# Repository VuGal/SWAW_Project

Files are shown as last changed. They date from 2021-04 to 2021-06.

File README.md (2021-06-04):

# SWAW_Project
Weather station project for SWAW course.

Android directory - contains the source code of the Android app which fetches the weather info from the server (along with prediction data)

Azure directory - contains the scripts related to weather prediction and database operations

Nucleo directory - contains the STM32 Nucleo source code (based on STM32CubeIDE) which is responsible for the communication with sensors and CAN communication with Raspberry Pi

PCB - contains the files related to the PCBs created for the project

Raspberry Pi - contains the Python scripts which are responsible for fetching the weather info via CAN bus and sending it to the server

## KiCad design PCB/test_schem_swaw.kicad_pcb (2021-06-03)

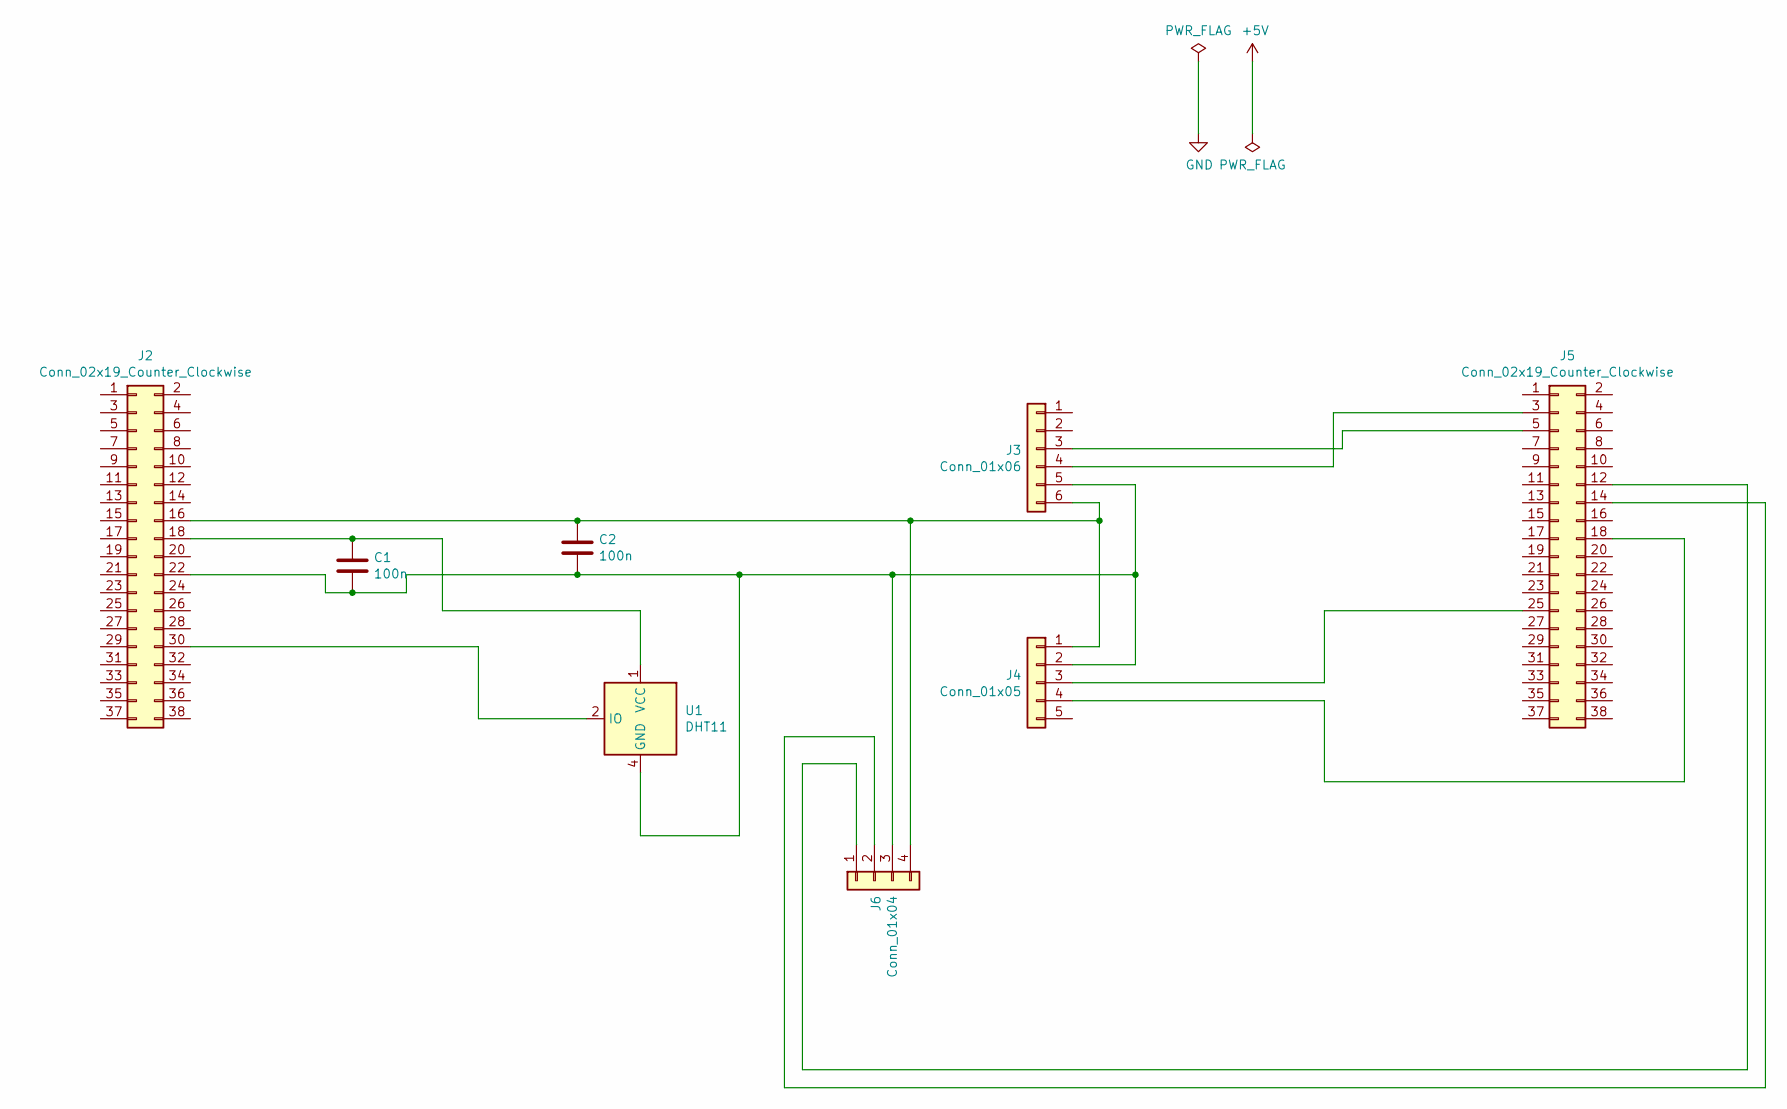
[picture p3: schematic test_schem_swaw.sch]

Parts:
C1, C2: 100n; C_Disc_D7.5mm_W4.4mm_P5.00mm
J2, J5: Conn_02x19_Counter_Clockwise; PinSocket_2x19_P2.54mm_Vertical
J3: Conn_01x06; PinSocket_1x06_P2.54mm_Vertical
J4: Conn_01x05; PinSocket_1x05_P2.54mm_Vertical
J6: Conn_01x04; PinSocket_1x04_P2.54mm_Vertical
U1: DHT11; Aosong_DHT11_5.5x12.0_P2.54mm

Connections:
unnamed: C1.1, J2.18, U1.1 (VCC)
unnamed: C1.2, C2.2, J2.22, J3.5, J4.2, J6.3, U1.4 (GND)
unnamed: C2.1, J2.16, J3.6, J4.1, J6.4
unnamed: J2.30, U1.2 (IO)
unnamed: J3.3, J5.5
unnamed: J3.4, J5.3
unnamed: J4.3, J5.25
unnamed: J4.4, J5.18
unnamed: J5.12, J6.1
unnamed: J5.14, J6.2

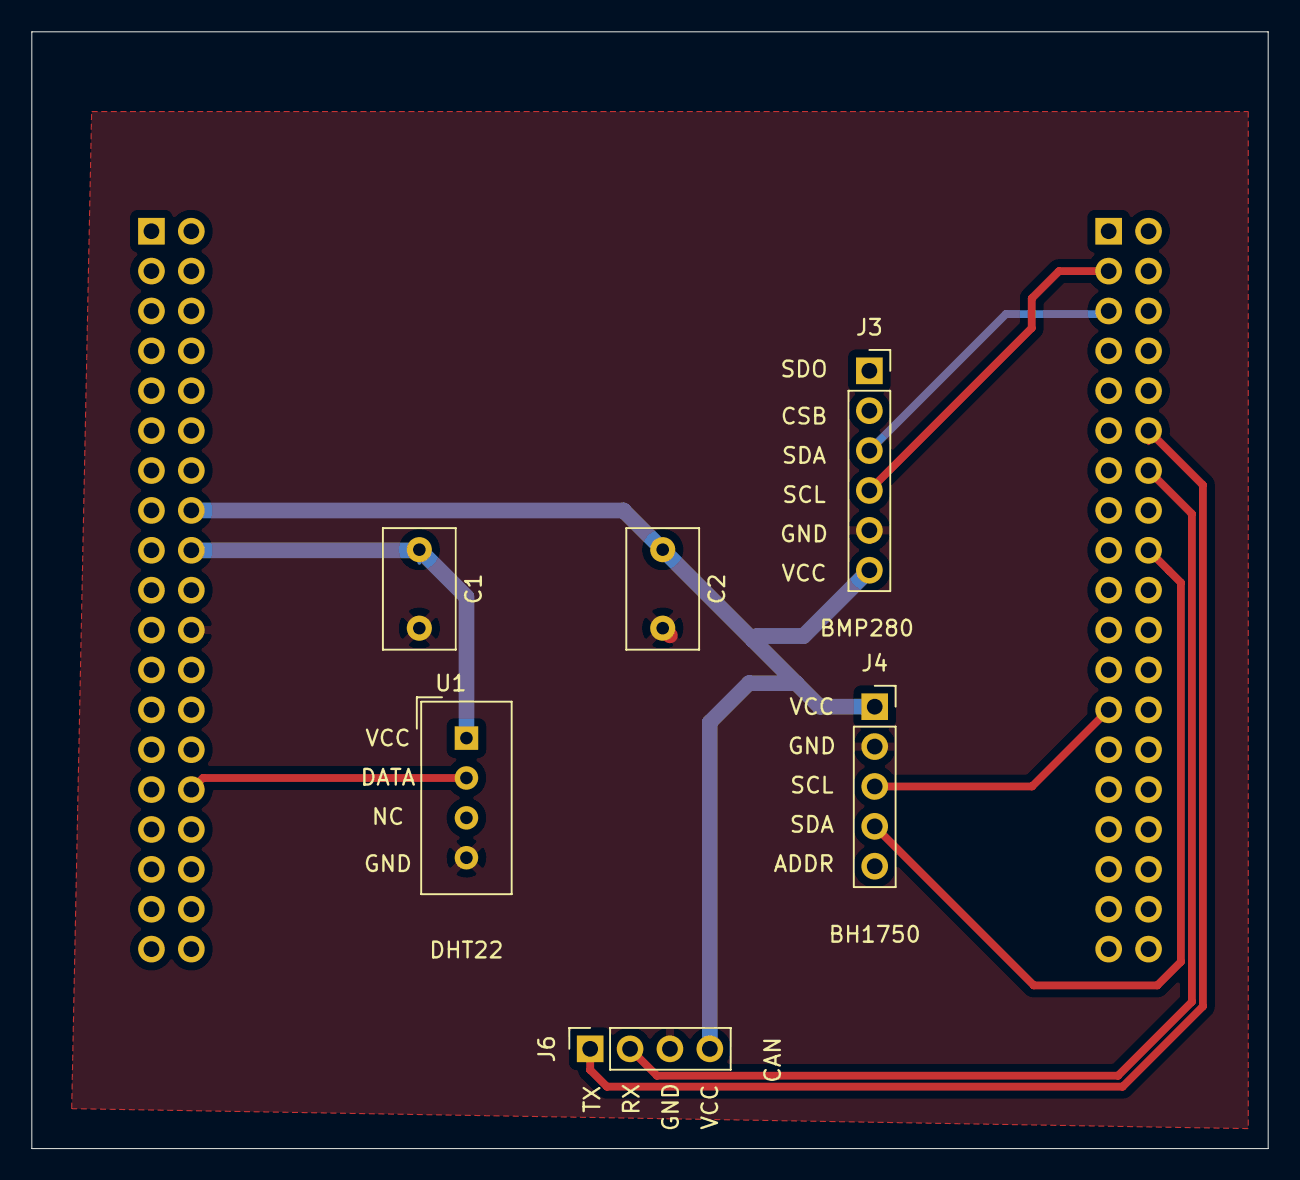
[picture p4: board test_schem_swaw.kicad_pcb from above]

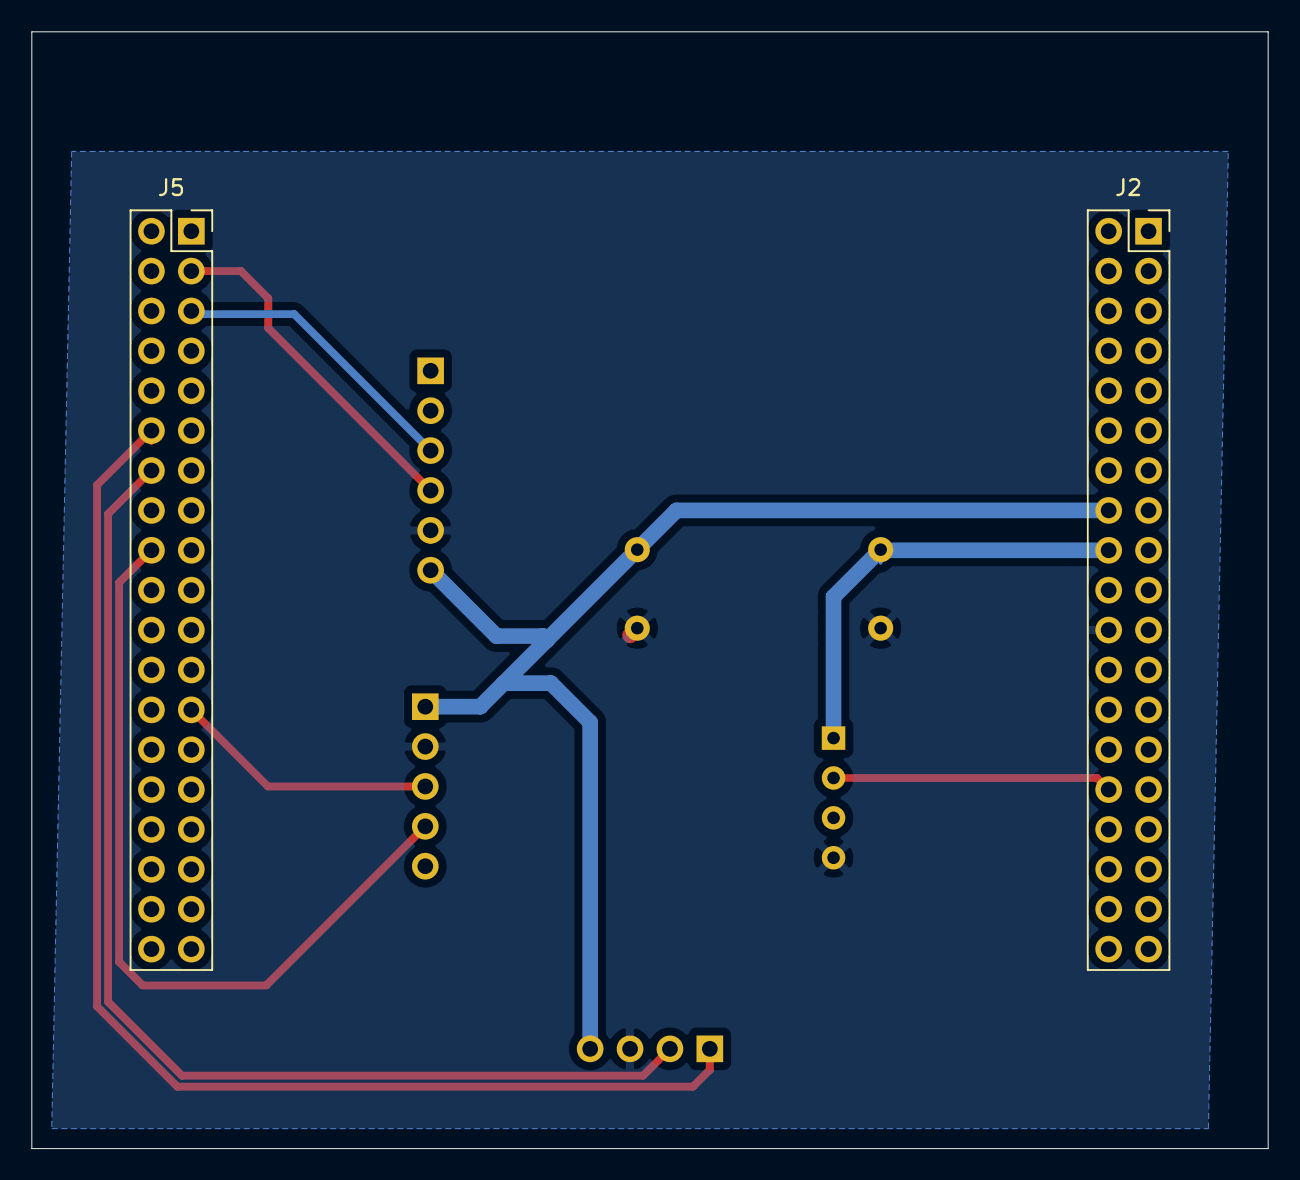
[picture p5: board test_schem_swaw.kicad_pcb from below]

Board: 4 copper layers, 78.7 x 71.1 mm, 8 parts (2 on the bottom side), 10 nets.

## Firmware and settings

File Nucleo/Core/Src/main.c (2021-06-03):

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
/* Includes ------------------------------------------------------------------*/
#include "main.h"

/* USER CODE BEGIN Includes */
#include "stdio.h"
#include "DHT22.h"
#include "BMP280.h"
#include "BH1750.h"

/* USER CODE END Includes */

CAN_HandleTypeDef hcan;

I2C_HandleTypeDef hi2c1;
I2C_HandleTypeDef hi2c2;

TIM_HandleTypeDef htim1;

/* USER CODE BEGIN PV */

CAN_FilterTypeDef sFilterConfig;
CAN_TxHeaderTypeDef TxHeader;
CAN_RxHeaderTypeDef RxHeader;
uint16_t TxData[4] = {0, 0, 0, 0};
uint16_t RxData[4] = {0, 0, 0, 0};
uint32_t TxMailbox;


uint8_t Rh_byte1, Rh_byte2, Temp_byte1, Temp_byte2;
uint16_t RH, TEMP;

float Temperature = 0;
float Humidity = 0;
uint8_t Presence = 0;
char message[10];


BMP280_HandleTypedef bmp280;
float pressureBmp280, temperatureBmp280, humidityBmp280;

uint16_t size;
uint8_t Data[256];

float BH1750_lux;

int init_iter = 0;

/* USER CODE END PV */

void SystemClock_Config(void);
static void MX_GPIO_Init(void);
static void MX_TIM1_Init(void);
static void MX_I2C1_Init(void);
static void MX_I2C2_Init(void);
static void MX_CAN_Init(void);
/**
  * @brief  The application entry point.
  * @retval int
  */
int main(void)
{
	/* MCU Configuration--------------------------------------------------------*/

	/* Reset of all peripherals, Initializes the Flash interface and the Systick. */
	HAL_Init();

	/* Configure the system clock */
	SystemClock_Config();

	/* Initialize all configured peripherals */
	MX_GPIO_Init();
	MX_TIM1_Init();
	MX_I2C1_Init();
	MX_I2C2_Init();
	MX_CAN_Init();

	/* USER CODE BEGIN 2 */

	// Timer start
	HAL_TIM_Base_Start(&htim1);

	// CAN filter parameters
	sFilterConfig.FilterBank = 0;
	sFilterConfig.FilterMode = CAN_FILTERMODE_IDMASK;
	sFilterConfig.FilterScale = CAN_FILTERSCALE_32BIT;
	sFilterConfig.FilterIdHigh = 0x0000;
	sFilterConfig.FilterIdLow = 0x0000;
	sFilterConfig.FilterMaskIdHigh = 0x0000;
	sFilterConfig.FilterMaskIdLow = 0x0000;
	sFilterConfig.FilterFIFOAssignment = CAN_RX_FIFO0;
	sFilterConfig.FilterActivation = ENABLE;
	sFilterConfig.SlaveStartFilterBank = 14;

	// CAN TX header parameters
	TxHeader.StdId = 0x321;
	TxHeader.ExtId = 0x01;
	TxHeader.RTR = CAN_RTR_DATA;
	TxHeader.IDE = CAN_ID_STD;
	TxHeader.DLC = 8;
	TxHeader.TransmitGlobalTime = DISABLE;

	// apply CAN filter configuration
	if (HAL_CAN_ConfigFilter(&hcan, &sFilterConfig) != HAL_OK)
	{
	  /* Filter configuration Error */
	  Error_Handler();
	}

	// start CAN bus operation
	if (HAL_CAN_Start(&hcan) != HAL_OK)
	{
	  /* Start Error */
	  Error_Handler();
	}

	// BMP280 parameters
	bmp280_init_default_params(&bmp280.params);
	bmp280.addr = BMP280_I2C_ADDRESS_0;
	bmp280.i2c = &hi2c1;

	// BMP280 initialization
	init_iter = 0;
	while (1) {

		if (bmp280_init(&bmp280, &bmp280.params)) break;
		else {
			HAL_Delay(1000);
			++init_iter;
		}

		if (init_iter > 100) Error_Handler();

	}

	// BH1750 initialization
	init_iter = 0;
	while (1) {

		if (BH1750_Init(&hi2c2) == BH1750_OK) break;
		else {
			HAL_Delay(1000);
			++init_iter;
		}

		if (init_iter > 100) Error_Handler();

	}
	BH1750_SetMode(CONTINUOUS_HIGH_RES_MODE_2);

	/* USER CODE END 2 */

	/* Infinite loop */
	/* USER CODE BEGIN WHILE */
	while (1)
	{
	/* USER CODE END WHILE */

	/* USER CODE BEGIN 3 */

	// DHT22 read-out
	DHT22_Start();
	Presence = DHT22_Check_Response();
	Rh_byte1 = DHT22_Read();
	Rh_byte2 = DHT22_Read();
	Temp_byte1 = DHT22_Read();
	Temp_byte2 = DHT22_Read();
	DHT22_Read();

	// bit operations needed for 2-byte representation
	TEMP = ((Temp_byte1<<8)|Temp_byte2);
	RH = ((Rh_byte1<<8)|Rh_byte2);

	// divide by 10
	Temperature = TEMP / 10;
	Humidity = RH / 10;

	// it seems that initial values of BMP280 are more accurate when this delay takes place
	HAL_Delay(1000);

	// BMP280 read-out
	init_iter = 0;
	while (1) {

		if (bmp280_read_float(&bmp280, &temperatureBmp280, &pressureBmp280, &humidityBmp280)) break;
		else {
			HAL_Delay(1000);
			++init_iter;
		}

		if (init_iter > 100) Error_Handler();

	}

	pressureBmp280 /= 100;

	// it seems that initial values of BH1750 are more accurate when this delay takes place
	HAL_Delay(1000);

	// BH1750 read-out
	BH1750_ReadLight(&BH1750_lux);

	// Data array filling
	TxData[0] = Temperature;
	TxData[1] = Humidity;
	TxData[2] = pressureBmp280;
	TxData[3] = BH1750_lux;

	// Send message on CAN TX
	HAL_CAN_AddTxMessage(&hcan, &TxHeader, (uint8_t *) TxData, &TxMailbox);

	// Get message from CAN RX
	HAL_CAN_GetRxMessage(&hcan, CAN_RX_FIFO0, &RxHeader, (uint8_t *) RxData);

	// 30 minutes delay
	HAL_Delay(180000);

  }
  /* USER CODE END 3 */
}

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
/* USER CODE BEGIN 4 */

void HAL_CAN_TxMailbox0CompleteCallback(CAN_HandleTypeDef *hcan)
{

}
void HAL_CAN_RxFifo0MsgPendingCallback(CAN_HandleTypeDef *hcan)
{
	HAL_CAN_GetRxMessage(hcan, CAN_RX_FIFO0, &RxHeader, (uint8_t *) RxData);
}



/* USER CODE END 4 */
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


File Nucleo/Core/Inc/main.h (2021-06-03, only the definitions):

#define DHT22_1Wire_Pin GPIO_PIN_1
#define DHT22_1Wire_GPIO_Port GPIOA
#define BH1750_I2C_SCL_Pin GPIO_PIN_10
#define BH1750_I2C_SCL_GPIO_Port GPIOB
#define BH1750_I2C_SDA_Pin GPIO_PIN_11
#define BH1750_I2C_SDA_GPIO_Port GPIOB
#define BMP280_I2C_SCL_Pin GPIO_PIN_8
#define BMP280_I2C_SCL_GPIO_Port GPIOB
#define BMP280_I2C_SDA_Pin GPIO_PIN_9
#define BMP280_I2C_SDA_GPIO_Port GPIOB

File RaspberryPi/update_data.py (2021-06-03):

import os
import can
import paramiko
from datetime import datetime


os.system('sudo ip link set can0 type can bitrate 250000')
os.system('sudo ifconfig can0 up')

can0 = can.interface.Bus(channel = 'can0', bustype = 'socketcan_ctypes')

date = str()


def log(message):
    with open('/home/pi/SWAW_Project/log.txt', 'a') as file:
        file.write(message+'\n')

def update_date():
    global date
    date = datetime.now().strftime("%Y-%m-%d %H:%M:%S")

def parse_can_frame(message):
    data = message.split()
    temperature = int(data[8]+data[7], 16)
    humidity = int(data[10]+data[9], 16)
    pressure = int(data[12]+data[11], 16)
    illuminance = int(data[14]+data[13], 16)
    return { 'temperature': str(temperature),\
             'humidity': str(humidity),\
             'pressure': str(pressure),\
             'illuminance': str(illuminance) }

def fetch_data_from_can_bus():
    msg = can0.recv(2400.00)
    if msg is not None:
        update_date()
        log(f'[{date}] Received some data!')
        data = parse_can_frame(str(msg))
        log(f'[{date}] Temperature: ' + data['temperature'] + ' °C')
        log(f'[{date}] Humidity: ' + data['humidity'] + ' %')
        log(f'[{date}] Pressure: ' + data['pressure'] + ' hPa')
        log(f'[{date}] Illuminance: ' + data['illuminance'] + ' Lx')
        ack_msg = can.Message(arbitration_id=0x123, data=[6, 5, 6, 7, 7, 6, 0, 0], extended_id=False)
        can0.send(ack_msg)
    else:
        log('Timeout occurred, no message received!')
    return data

def save_to_text_file(values):
    with open('/home/pi/SWAW_Project/data.txt', 'w') as file:
        file.write(date+'\n')
        file.write('Temperature: ' + values['temperature'] + '\n')
        file.write('Humidity: ' + values['humidity'] + '\n')
        file.write('Pressure: ' + values['pressure'] + '\n')
        file.write('Illuminance: ' + values['illuminance'] + '\n')

def save_to_html_file(values):
    with open('/home/pi/SWAW_Project/index.html', 'w') as file:
        file.write('<div id="Date">' + date + '</div>\n')
        file.write('<div id="Temperature">' + values['temperature'] + '</div>\n')
        file.write('<div id="Humidity">' + values['humidity'] + '</div>\n')
        file.write('<div id="Pressure">' + values['pressure'] + '</div>\n')
        file.write('<div id="Illuminance">' + values['illuminance'] + '</div>')

def send_html_file(file_path):
    ssh = paramiko.SSHClient()
    ssh.load_host_keys('/home/pi/.ssh/known_hosts')
    ssh.connect('23.102.182.59', username='swawproject')
    sftp = ssh.open_sftp()
    sftp.put(file_path, '/var/www/html/index.html')
    sftp.close()
    ssh.close()

if __name__ == '__main__':
    while True:
        update_date()
        log(f'[{date}] Waiting for new sensor values...\n')
        try:
            sensor_values = fetch_data_from_can_bus()
            log(f'[{date}] Fetching sensor values - SUCCESS!')
        except:
            log(f'[{date}] Fetching sensor values - ERROR!')
            continue
        log(f'[{date}] Saving sensor values to text file...')
        try:
            save_to_text_file(sensor_values)
            log(f'[{date}] Saving to text file - SUCCESS!')
        except:
            log(f'[{date}] Saving to text file - ERROR!')
        log(f'[{date}] Saving sensor values to HTML file...')
        try:
            save_to_html_file(sensor_values)
            log(f'[{date}] Saving to HTML file - SUCCESS!')
        except:
            log(f'[{date}] Saving to HTML file - ERROR!')
            continue
        log(f'[{date}] Sending HTML file to the remote server...')
        try:
            send_html_file('/home/pi/SWAW_Project/index.html')
            log(f'[{date}] Sending HTML file to remote server - SUCCESS!')
        except:
            log(f'[{date}] Sending HTML file to remote server - ERROR!')

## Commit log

2021-04-22 Add PCB schematics
    [test_schem_swaw.kicad_pcb, test_schem_swaw.sch, test_schem_swaw_raps.kicad_pcb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]
2021-05-01 DHT22 sensor working
2021-06-03 Full Nucleo application
    Includes handling of all three sensors (DHT22, BMP280, BH1750) and
    working CAN bus transmission.
2021-06-03 Updated version of Raspberry Pi Python scripts
2021-06-03 Modified scheme of PCB - final version, not developed anymore
    [test_schem_swaw.kicad_pcb, test_schem_swaw.sch]

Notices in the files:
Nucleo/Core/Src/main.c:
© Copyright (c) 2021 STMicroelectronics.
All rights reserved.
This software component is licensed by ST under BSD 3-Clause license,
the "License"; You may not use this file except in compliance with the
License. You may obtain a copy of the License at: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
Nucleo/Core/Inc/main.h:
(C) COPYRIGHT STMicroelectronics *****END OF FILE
